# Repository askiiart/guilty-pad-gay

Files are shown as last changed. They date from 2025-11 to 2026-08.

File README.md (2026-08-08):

# GUILTY PAD -GAY-

Look this was gonna be normal but then the woke left made me add yuri

---

This is a macro pad which is designed with the [Guilty Pad XX Accent Core Plus Yuri](https://github.com/askiiart/guilty-pad-xx-accent-core-plus-yuri) in mind - can either act independently, or with the right firmware, could theoretically act as a very weird split keyboard. If you wanna get really crazy, it even has exposed i2c for expandability. For now it just includes very basic kmk firmware for testing.

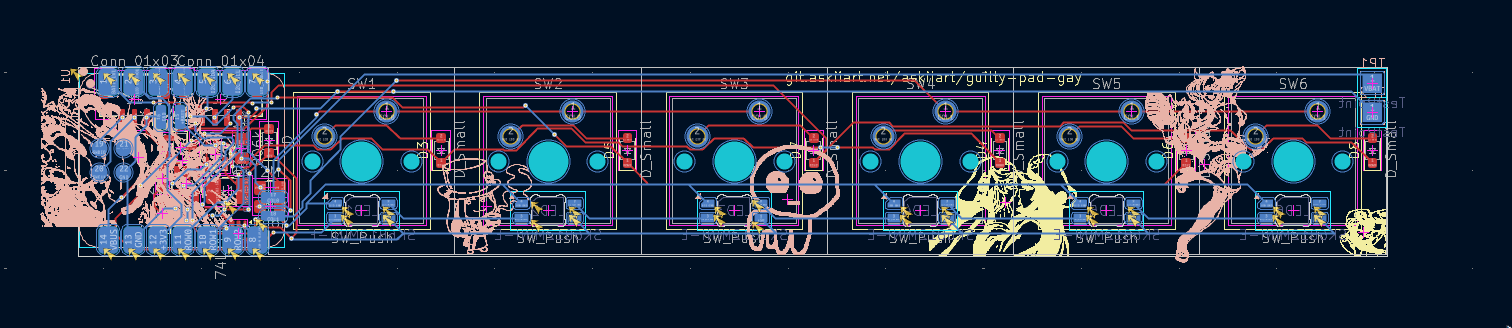
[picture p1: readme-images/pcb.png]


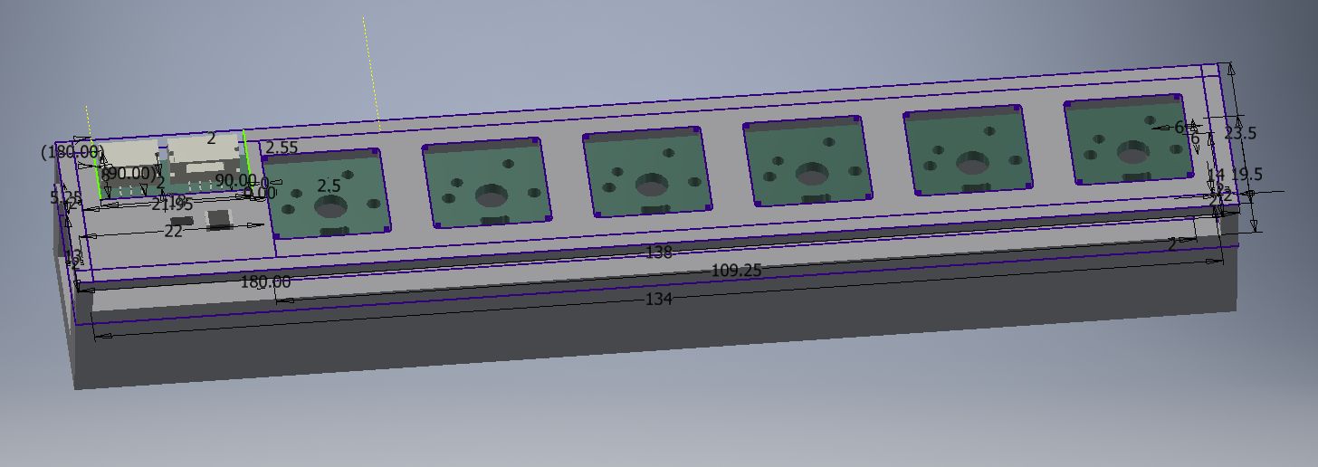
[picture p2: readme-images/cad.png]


## Bill of Materials

|Name |Quantity needed|MOQ|Price |Quantity to order|Link |Total |
|---|---|---|---|---|---|---|
|Xiao nRF52840 |1 |1  |9.99  |1 |<https://www.seeedstudio.com/Seeed-XIAO-BLE-nRF52840-p-5201.html>|9.99 |
|903090 lipo |1 |1  |11.69 |1 |<https://www.aliexpress.us/item/3256809116041100.html> |11.69 |
|AO3400A |1 |20 |0.0214|20 |<https://www.lcsc.com/product-detail/C49195711.html> |0.428 |
|AO3401A |1 |20 |0.0321|20 |<https://www.lcsc.com/product-detail/C347476.html> |0.642 |
|1N5819WS |8 |100|0.0107|100 |<https://www.lcsc.com/product-detail/C191023.html> |1.07 |
|74LV1T08GW-TP |1 |10 |0.0609|10 |<https://www.lcsc.com/product-detail/C42460230.html> |0.609 |
|TPS613222ADBVR |1 |5  |0.1574|5 |<https://www.lcsc.com/product-detail/C2071163.html> |0.787 |
|Inductor |1 |5  |0.1508|5 |<https://www.lcsc.com/product-detail/C17701271.html> |0.754 |
|SK6803MINI-E |6 |10 |0.085 |10 |<https://www.lcsc.com/product-detail/C5242955.html> |0.85 |
|22uF cap |1 |20 |0.0354|20 |<https://www.lcsc.com/product-detail/C577040.html> |0.708 |
|2M resistor |1 |10 |0.0468|10 |<https://www.lcsc.com/product-detail/C2984387.html> |0.468 |
|820k resistor |2 |20 |0.0499|20 |<https://www.lcsc.com/product-detail/C865663.html> |0.998 |
| | | | | | | |
| | | | | | | |
|seeed studio shipping| | | | | |5.46 |
|LCSC shipping | | | | | |11.31 |
| | | | | | | |
| | | | | | | |
|Subtotal | | | | | |45.764  |
|Total | | | | | |49.53953|

## Art

- [bridget](https://danbooru.donmai.us/posts/10037913)
- [mayburi](https://danbooru.donmai.us/posts/10155469)
- [testament](https://x.com/kujikawaii/status/1534858361476358144)
- [elphelt](https://static.wikia.nocookie.net/guilty-gear/images/4/44/Elphelt_Guilty_Gear_Strive.png/revision/latest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) (from the elphelt fandom page)
- [other mayburi](https://danbooru.donmai.us/posts/9990984)

## Notes

- You can swap out the SK6803s for SK6812s, just keep in mind to account for them obviously being much brighter, and SK6803s have better color at low brightness.

## Assembly

Just solder the components as is obvious, then the case just slides together - it should be able to stay together on its own just fine, but it can also be glued or welded lightly if needed.

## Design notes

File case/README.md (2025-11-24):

# Case files

This folder contains stuff relating to the case

- layout.dxf: the dxf file containing the layout, as generate by [aio3 plate generator](https://kbplate.ai03.com/)
  - note: despite it not affecting the output, the plate generator breaks if the keys don't have labels/legends

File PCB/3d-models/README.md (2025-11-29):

# 3d model sources

- [1N4001](https://grabcad.com/library/diode-1n4001-1)
- [XIAO nrf52840](https://www.printables.com/model/1336692-3d-model-for-seeed-studio-xiao-nrf52840)
- [SK6812MINI-E](https://grabcad.com/library/sk6812mini-e-led-1)

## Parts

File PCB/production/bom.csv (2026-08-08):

Designator | Footprint | Quantity | Value | LCSC Part #
C2 | 0603 | 1 | 22uF
D1, D2 | D_SOD-323_HandSoldering | 2 | D
D3, D4, D5, D6, D7, D8 | D_SOD-323_HandSoldering | 6 | D_Small
J1 | JST_GH_SM03B-GHS-TB_1x03-1MP_P1.25mm_Horizontal | 1 | Conn_01x03
J2 | JST_GH_SM04B-GHS-TB_1x04-1MP_P1.25mm_Horizontal | 1 | Conn_01x04
L1 | 1210 | 1 | 4.7uH
LED1, LED2, LED3, LED4, LED5, LED6 | LED_6028R | 6 | SK6812MINI-E
Q1 | SOT-23 | 1 | AO3400A
Q2 | SOT-23 | 1 | AO3401A
R1, R3 | 0805 | 2 | 806k
R2 | 0805 | 1 | 2M
SW1, SW2, SW3, SW4, SW5, SW6 | SW_Cherry_MX_1.00u_PCB | 6 | SW_Push
TP1, TP2 | TestPoint_Pad_2.0x2.0mm | 2 | TestPoint
U1 | XIAO-nRF52840-SMD | 1 | XIAO-nRF52840-SMD
U2 | SOT-23-5 | 1 | TPS613222ADBV
U3 | SOT-353_SC-70-5 | 1 | 74LV1T08GW

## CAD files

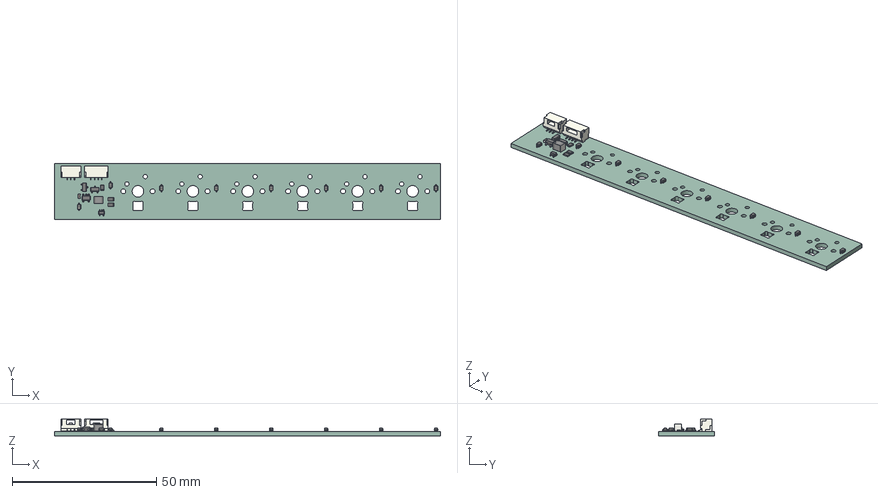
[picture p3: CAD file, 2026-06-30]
case/pcb.step
133.8 x 19.4 x 5.84 mm
D_SOD-323 x 8
SOT-23 x 2
SOT-353_SC-70-5
JST_SM03B_GHS_TB
C_0603_1608Metric
R_0805_2012Metric x 3
L_1210_3225Metric
SOT-23-5
JST_SM04B_GHS_TB
guilty-pad-gay_PCB

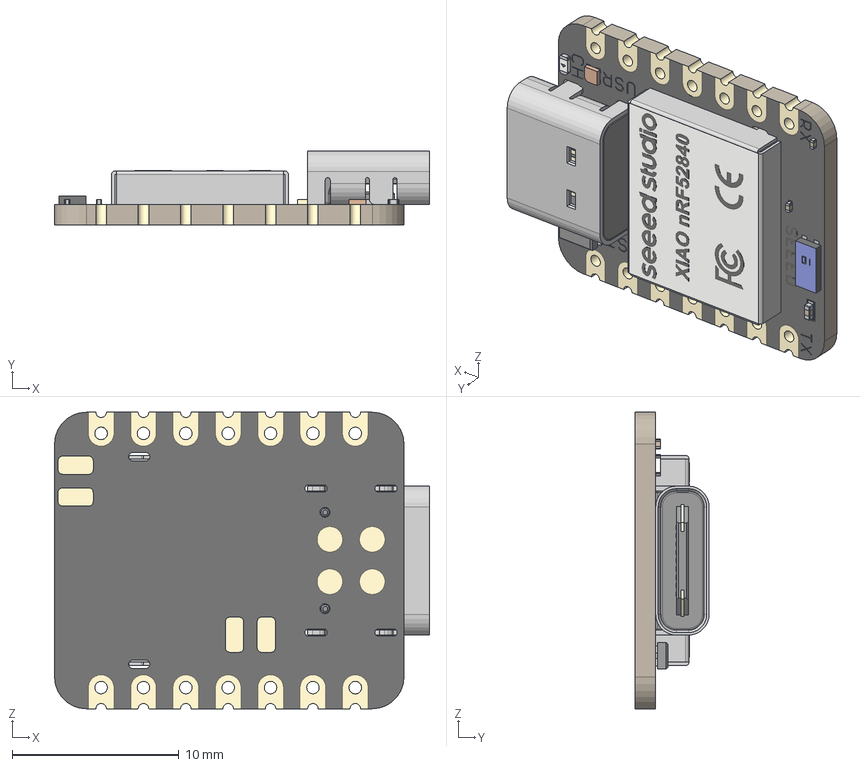
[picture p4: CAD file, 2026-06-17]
PCB/3d-models/xiao-nrf52840-v3.step
22.5 x 4.46 x 17.8 mm
BOSS-EXTRUDE14_8_
BOSS-EXTRUDE7_4_
BOSS-EXTRUDE7_3_
BOSS-EXTRUDE14_4_
BOSS-EXTRUDE14_2_
BOSS-EXTRUDE14_11_
BOSS-EXTRUDE7_7_
BOSS-EXTRUDE14_9_
BOSS-EXTRUDE14_3_
BOSS-EXTRUDE14_7_
MIRROR2
BOSS-EXTRUDE14_5_
BOSS-EXTRUDE14_12_
BOSS-EXTRUDE7_8_
BOSS-EXTRUDE7_1_
BOSS-EXTRUDE14_10_
BOSS-EXTRUDE7_9_
BOSS-EXTRUDE14_6_
BOSS-EXTRUDE14_1_
BOSS-EXTRUDE7_6_
BOSS-EXTRUDE7_2_
CUT-EXTRUDE5
BOSS-EXTRUDE7_5_
Shield
Pins
CAP x 2
ANT1
Silkscreen
CAP 3
LED
USR
MSM261D3526H1CPM

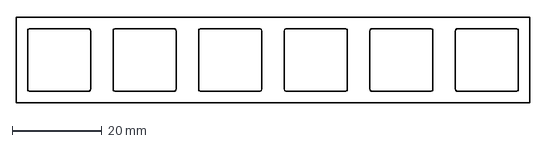
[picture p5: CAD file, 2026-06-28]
case/layout.dxf
114.3 x 19.1 mm

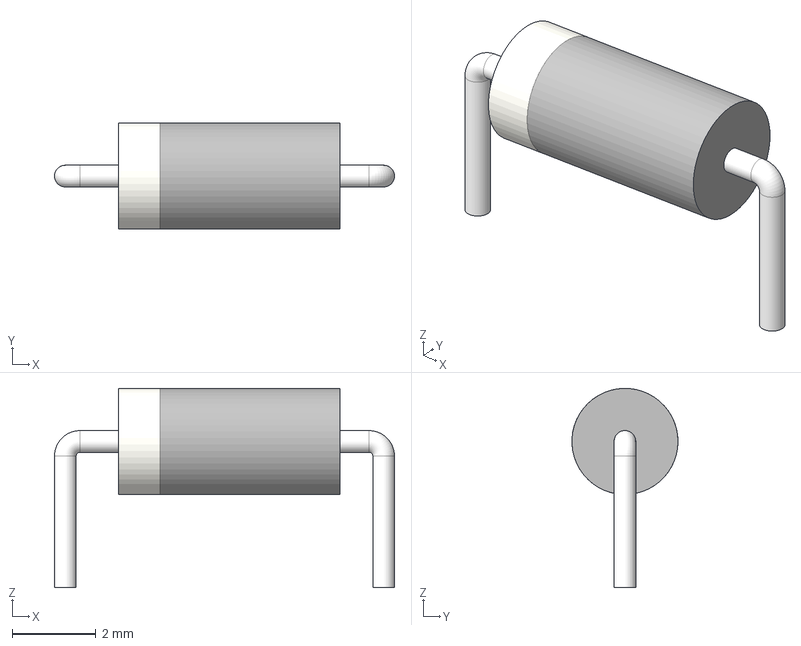
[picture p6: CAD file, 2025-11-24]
PCB/3d-models/diode 1N4001.step
8.14 x 2.54 x 4.77 mm

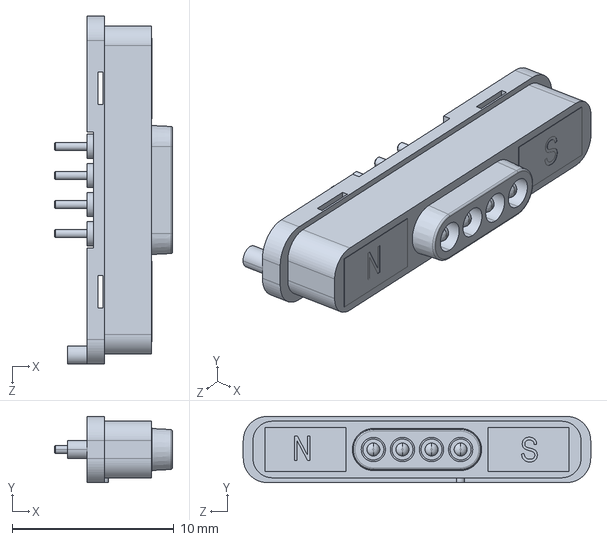
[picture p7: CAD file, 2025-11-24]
PCB/3d-models/685L0421250110E.STEP
7.30 x 4.10 x 21.5 mm

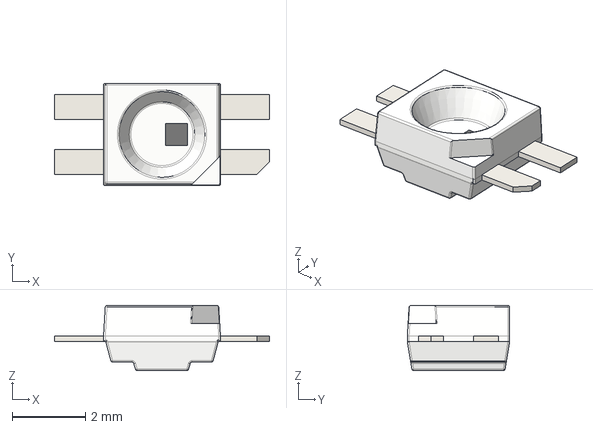
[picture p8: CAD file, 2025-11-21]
PCB/3d-models/LED_SK6812MINI-E.step
5.88 x 2.80 x 1.78 mm

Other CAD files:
case/C_0603_1608Metric.iam
case/C_0603_1608Metric.ipt
case/D_SOD-323.iam
case/D_SOD-323.ipt
case/JST_GH_SM03B-GHS-TB_1x03-1MP_P1.25mm_Horizontal.iam
case/JST_GH_SM04B-GHS-TB_1x04-1MP_P1.25mm_Horizontal.iam
case/JST_SM03B_GHS_TB.ipt
case/JST_SM04B_GHS_TB.ipt
case/L_1210_3225Metric.iam
case/L_1210_3225Metric.ipt
case/OldVersions/case-bottom.0003.ipt
case/OldVersions/case-top.0009.ipt
case/R_0805_2012Metric.iam
case/R_0805_2012Metric.ipt
case/SOT-23-5.iam
case/SOT-23-5.ipt
case/SOT-23.iam
case/SOT-23.ipt
case/SOT-353_SC-70-5.iam
case/SOT-353_SC-70-5.ipt
case/assembly.iam
case/case-bottom.ipt
case/case-top.ipt
case/guilty-pad-gay_PCB.ipt
case/pcb.iam

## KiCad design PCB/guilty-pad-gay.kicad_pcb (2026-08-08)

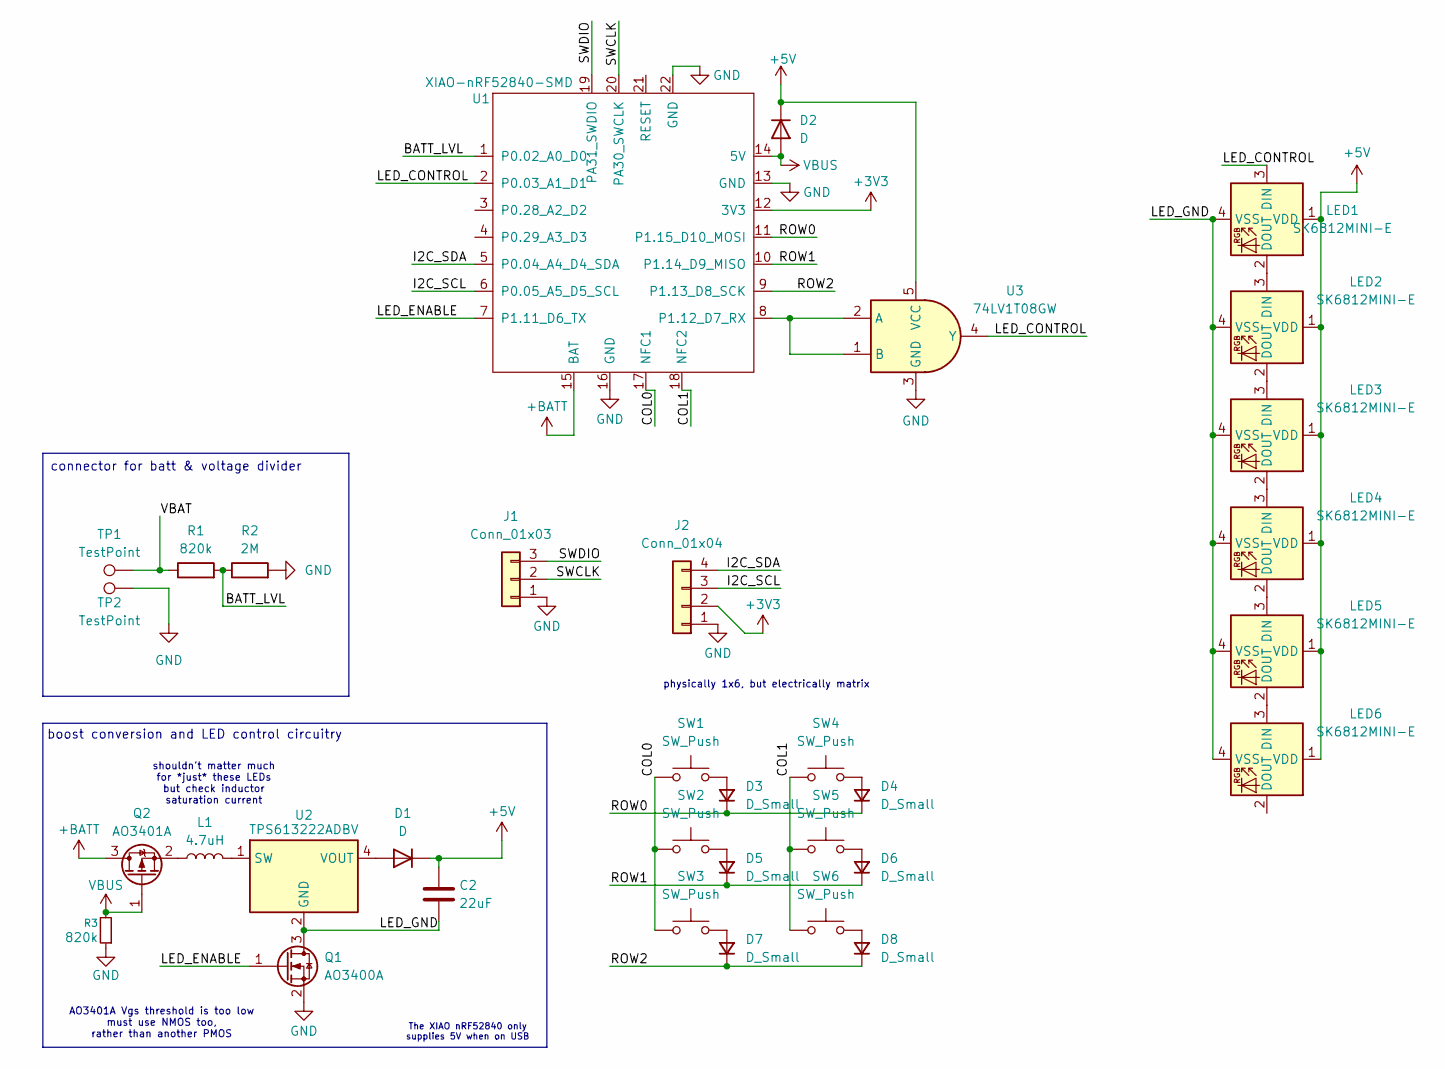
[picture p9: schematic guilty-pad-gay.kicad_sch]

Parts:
C2: 22uF; C_0603_1608Metric_Pad1.08x0.95mm_HandSolder
D1, D2: D; D_SOD-323_HandSoldering
D3, D4, D5, D6, D7, D8: D_Small; D_SOD-323_HandSoldering
J1: Conn_01x03; JST_GH_SM03B-GHS-TB_1x03-1MP_P1.25mm_Horizontal
J2: Conn_01x04; JST_GH_SM04B-GHS-TB_1x04-1MP_P1.25mm_Horizontal
L1: 4.7uH; L_1210_3225Metric_Pad1.42x2.65mm_HandSolder
LED1, LED2, LED3, LED4, LED5, LED6: SK6812MINI-E; LED_6028R
Q1: AO3400A; SOT-23
Q2: AO3401A; SOT-23
R1, R3: 820k; R_0805_2012Metric_Pad1.20x1.40mm_HandSolder
R2: 2M; R_0805_2012Metric_Pad1.20x1.40mm_HandSolder
SW1, SW2, SW3, SW4, SW5, SW6: SW_Push; SW_Cherry_MX_1.00u_PCB
TP1, TP2: TestPoint; TestPoint_Pad_2.0x2.0mm
U1: XIAO-nRF52840-SMD
U2: TPS613222ADBV; SOT-23-5
U3: 74LV1T08GW; SOT-353_SC-70-5

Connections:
+3V3: J2.2, U1.12 (3V3)
+5V: C2.2, D1.1 (K), D2.1 (K), LED1.1 (VDD), LED2.1 (VDD), LED3.1 (VDD), LED4.1 (VDD), LED5.1 (VDD), LED6.1 (VDD), U3.5 (VCC)
+BATT: Q2.3 (D), U1.15 (BAT)
/BATT_LVL: R1.2, R2.1, U1.1 (P0.02_A0_D0)
/COL0: SW1.1, SW2.1, SW3.1, U1.17 (NFC1)
/COL1: SW4.1, SW5.1, SW6.1, U1.18 (NFC2)
/I2C_SCL: J2.3, U1.6 (P0.05_A5_D5_SCL)
/I2C_SDA: J2.4, U1.5 (P0.04_A4_D4_SDA)
/LED_CONTROL: LED1.3 (DIN), U1.2 (P0.03_A1_D1), U3.4 (Y)
/LED_ENABLE: Q1.1 (G), U1.7 (P1.11_D6_TX)
/LED_GND: C2.1, LED1.4 (VSS), LED2.4 (VSS), LED3.4 (VSS), LED4.4 (VSS), LED5.4 (VSS), LED6.4 (VSS), Q1.3 (D), U2.2 (GND)
/ROW0: D3.1 (K), D4.1 (K), U1.11 (P1.15_D10_MOSI)
/ROW1: D5.1 (K), D6.1 (K), U1.10 (P1.14_D9_MISO)
/ROW2: D7.1 (K), D8.1 (K), U1.9 (P1.13_D8_SCK)
/SWCLK: J1.2, U1.20 (PA30_SWCLK)
/SWDIO: J1.3, U1.19 (PA31_SWDIO)
/VBAT: R1.1, TP1.1 (1_1)
GND: J1.1, J2.1, Q1.2 (S), R2.2, R3.1, TP2.1 (1_1), U1.13 (GND), U1.16 (GND), U1.22 (GND), U3.3 (GND)
unnamed: D1.2 (A), U2.4 (VOUT)
unnamed: D3.2 (A), SW1.2
unnamed: D4.2 (A), SW4.2
unnamed: D5.2 (A), SW2.2
unnamed: D6.2 (A), SW5.2
unnamed: D7.2 (A), SW3.2
unnamed: D8.2 (A), SW6.2
unnamed: LED1.2 (DOUT), LED2.3 (DIN)
unnamed: LED2.2 (DOUT), LED3.3 (DIN)
unnamed: LED3.2 (DOUT), LED4.3 (DIN)
unnamed: LED4.2 (DOUT), LED5.3 (DIN)
unnamed: LED5.2 (DOUT), LED6.3 (DIN)
unnamed: L1.1, Q2.2 (S)
unnamed: U1.8 (P1.12_D7_RX), U3.1 (B), U3.2 (A)
unnamed: L1.2, U2.1 (SW)
VBUS: D2.2 (A), Q2.1 (G), R3.2, U1.14 (5V)

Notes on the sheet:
physically 1x6, but electrically matrix
shouldn't matter much for *just* these LEDs but check inductor saturation current
boost conversion and LED control circuitry
AO3401A Vgs threshold is too low must use NMOS too, rather than another PMOS
connector for batt & voltage divider
The XIAO nRF52840 only supplies 5V when on USB

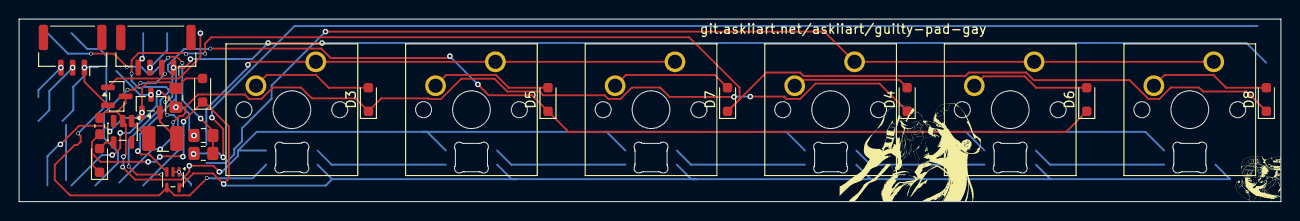
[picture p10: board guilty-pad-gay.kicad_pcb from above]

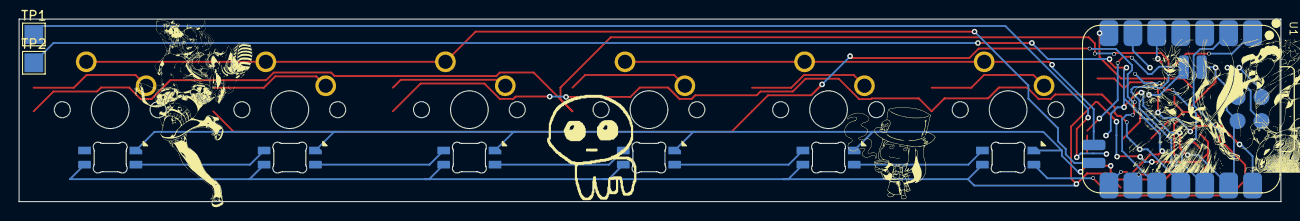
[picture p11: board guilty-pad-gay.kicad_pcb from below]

Board: 2 copper layers, 133.8 x 19.4 mm, 34 parts (9 on the bottom side), 34 nets.

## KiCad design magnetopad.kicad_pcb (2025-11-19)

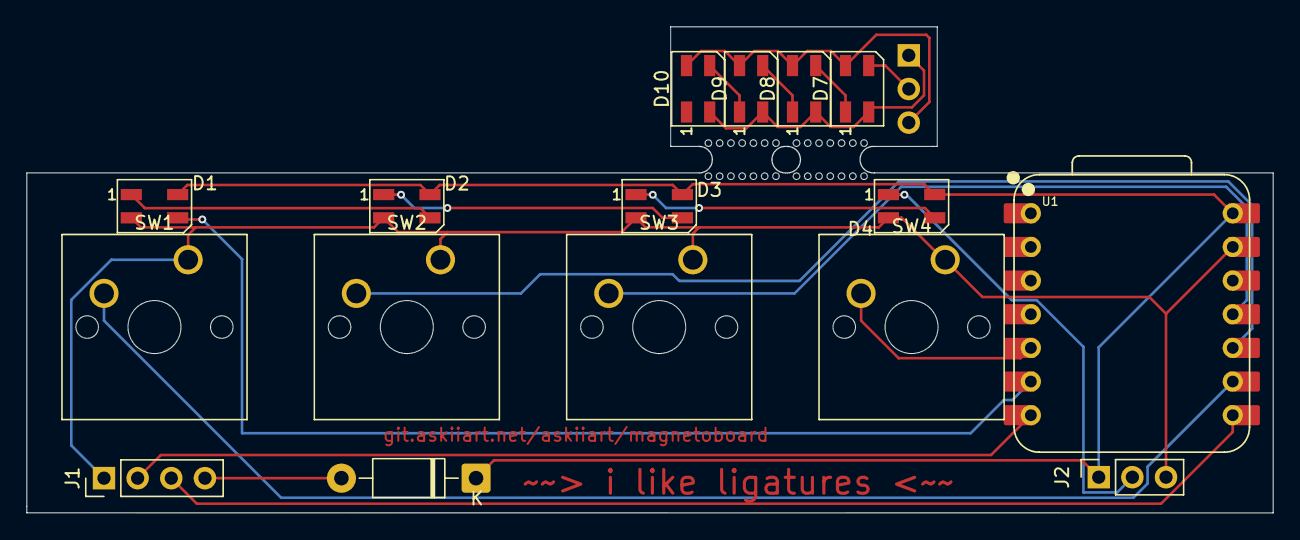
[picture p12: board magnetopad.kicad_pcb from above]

Board: 2 copper layers, 94.1 x 36.7 mm, 17 parts (1 on the bottom side), 20 nets.

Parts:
D1, D2, D3, D4, D7, D8, D9, D10: SK6812MINI; LED_SK6812MINI_PLCC4_3.5x3.5mm_P1.75mm
D6: 1N4001; D_DO-41_SOD81_P10.16mm_Horizontal
J1: 1N4001 (diode); PinHeader_1x04_P2.54mm_Vertical
J2, J3: Conn_01x03_Socket; PinSocket_1x03_P2.54mm_Vertical
SW1: MX switches; SW_Cherry_MX_1.00u_PCB
SW2, SW3, SW4: SW_Push; SW_Cherry_MX_1.00u_PCB
U1: XIAO RP2040; XIAO-RP2040-DIP

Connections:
+5V: D1.4 (VDD), D2.4 (VDD), D3.4 (VDD), D4.4 (VDD), D6.1 (K), J2.1, U1.14 (VBUS)
+5V_LED_board: D7.4 (VDD), D8.4 (VDD), D9.4 (VDD), D10.4 (VDD), J3.3
GND: D1.2 (VSS), D2.2 (VSS), D3.2 (VSS), D4.2 (VSS), J1.1, J2.3, SW1.1, SW2.1, SW3.1, SW4.1, U1.13 (GND)
GND_LED_board: D7.2 (VSS), D8.2 (VSS), D9.2 (VSS), D10.2 (VSS), J3.1
unnamed: D1.3 (DIN), U1.6 (GPIO7/SCL)
unnamed: D1.1 (DOUT), D2.3 (DIN)
unnamed: D2.1 (DOUT), D3.3 (DIN)
unnamed: D3.1 (DOUT), D4.3 (DIN)
unnamed: D4.1 (DOUT), J2.2
unnamed: D6.2 (A), J1.4
unnamed: D7.3 (DIN), J3.2
unnamed: D7.1 (DOUT), D8.3 (DIN)
unnamed: D8.1 (DOUT), D9.3 (DIN)
unnamed: D9.1 (DOUT), D10.3 (DIN)
unnamed: J1.2, U1.7 (GPIO0/TX)
unnamed: J1.3, U1.8 (GPIO1/RX)
unnamed: SW1.2, U1.9 (GPIO2/SCK)
unnamed: SW3.2, U1.11 (GPIO3/MOSI)
unnamed: SW2.2, U1.10 (GPIO4/MISO)
unnamed: SW4.2, U1.5 (GPIO6/SDA)

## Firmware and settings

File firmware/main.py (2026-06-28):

import board
from kmk.kmk_keyboard import KMKKeyboard
from kmk.keys import KC
from kmk.scanners import DiodeOrientation

keyboard = KMKKeyboard()

# Define your GPIO pins - adjust these to match your actual wiring
keyboard.col_pins = (board.P0_09, board.P0_10)
keyboard.row_pins = (board.P1_15, board.P1_14, board.P1_13)  # Empty since you're not using a matrix

keyboard.diode_orientation = DiodeOrientation.COL2ROW

# Define your keymap - one layer with 4 keys
keyboard.keymap = [
    [KC.MUTE, KC.VOLU, KC.VOLD, KC.MPLY, KC.COPY, KC.PASTE]  # Replace with whatever keys you want
]

if __name__ == '__main__':
    keyboard.go()

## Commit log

2025-11-19 initial version - routed and passes DRC
    [magnetopad.kicad_pcb, magnetopad.kicad_sch]
2025-11-19 update README, add custom lib with socket for pogo assembly
2025-11-21 - update to use the right LEDs (SK6812MINI-E) (added marbastlib for that) - redo the board a bit so it actually lines up with the keycap grid decently - add art :3
    [LED_SK6812MINI-E.step, Seeed Studio XIAO RP2040 v26.step, diode 1N4001.step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]
2025-11-24 - add case - rename
    [685L0421250110E.STEP, case-bottom.f3d, case-top.f3d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]
2025-11-29 switch to nrf, add boost converter stuff for running LEDs off battery, and update the README
    [guilty-pad-gay.kicad_sch]
2025-11-29 update case, minor pcb updates. should be ready to submit
    [case-bottom.f3d, case-top.f3d, guilty-pad-gay.kicad_sch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]
2025-11-29 swap out the capacitor for a bigger one - can use it for both this and the full-size board
    [guilty-pad-gay.kicad_sch]
2025-11-30 swap to 5V and use level shifter - much more sane
    [guilty-pad-gay.kicad_sch]
2025-11-30 i forgor to swap out text, that's all
    [guilty-pad-gay.kicad_sch]
2026-06-17 look idek i just want this in git
    [685L0421250110E.STEP, LED_SK6812MINI-E.step, Seeed Studio XIAO RP2040 v26.step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]
2026-06-22 look idr what's different but uh yeag i'm committing
    [guilty-pad-gay.kicad_sch]
2026-06-28 update with routed and parts and stuffs
    [guilty-pad-gay.kicad_pcb, guilty-pad-gay.kicad_sch]
2026-06-28 add BOM and update image
    [BOM.csv, BOM.ods, guilty-pad-gay.kicad_pcb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]
2026-06-28 add new cad
    [case-bottom.0003.ipt, case-bottom.f3d, case-bottom.ipt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]
2026-06-29 add holes for keys
    [case-top.0007.ipt, case-top.0009.ipt, case-top.ipt]
2026-06-30 add assembled cad
    [C_0603_1608Metric.iam, C_0603_1608Metric.ipt, D_SOD-323.iam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]
2026-06-30 remove temporary BOM
2026-08-08 i think i may have had some uncommitted changes oops
    also delete lock files
    [bom.csv, designators.csv, guilty-pad-gay.kicad_pcb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]
2026-10-20 add schematic image, rerun prod to make sure it's up to date
